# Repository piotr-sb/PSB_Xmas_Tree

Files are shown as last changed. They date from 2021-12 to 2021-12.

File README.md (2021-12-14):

# PSB_Xmas_Tree
PCB Xmas tree with LEDs

This little and fun project was created to bring smile to peoples face durig Xmas.

It is USB powered, easy to make Christmas tree with minimal number of components.

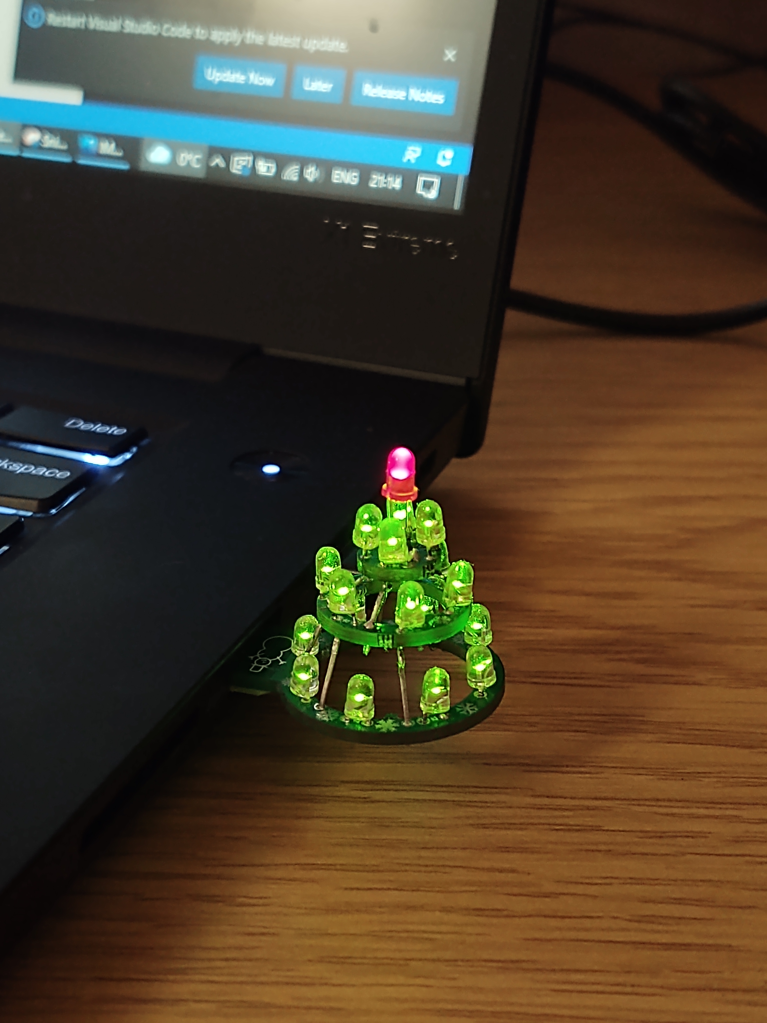
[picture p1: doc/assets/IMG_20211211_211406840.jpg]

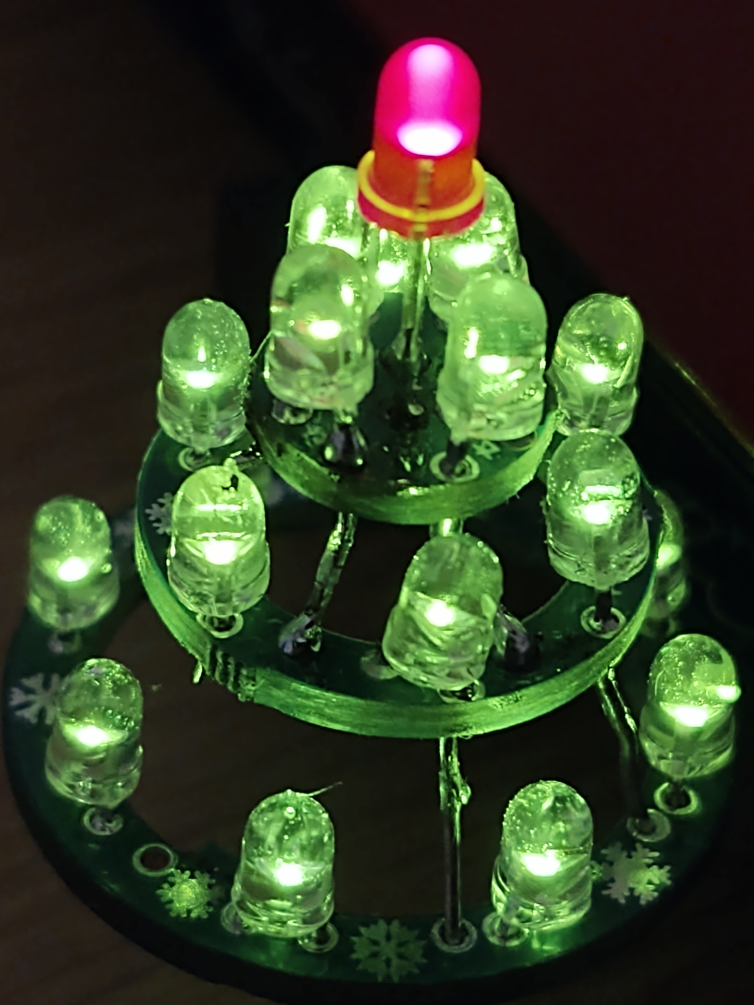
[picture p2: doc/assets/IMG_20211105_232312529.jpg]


## List of parts:
- 18x GREEN 3mm, THT LED
- 1x RED 3mm, THT LED
- 19x 1k 0603 resistor
- PCB

PCB was ordered from JLCPCB:

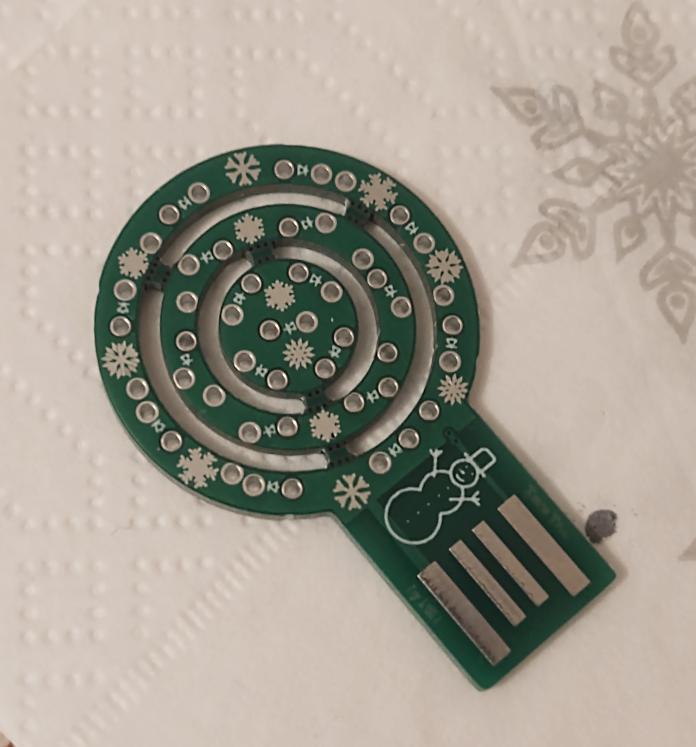
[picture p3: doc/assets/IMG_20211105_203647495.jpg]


LEDs legs are used also as mechanical support connecting layers together and providing power and GND. From each LED one leg needs to be cut short and the other one needs to be soldered to the layer below, because some of the connections are GND and some of them are +5V they can't be missmached, the connections should be as follows:

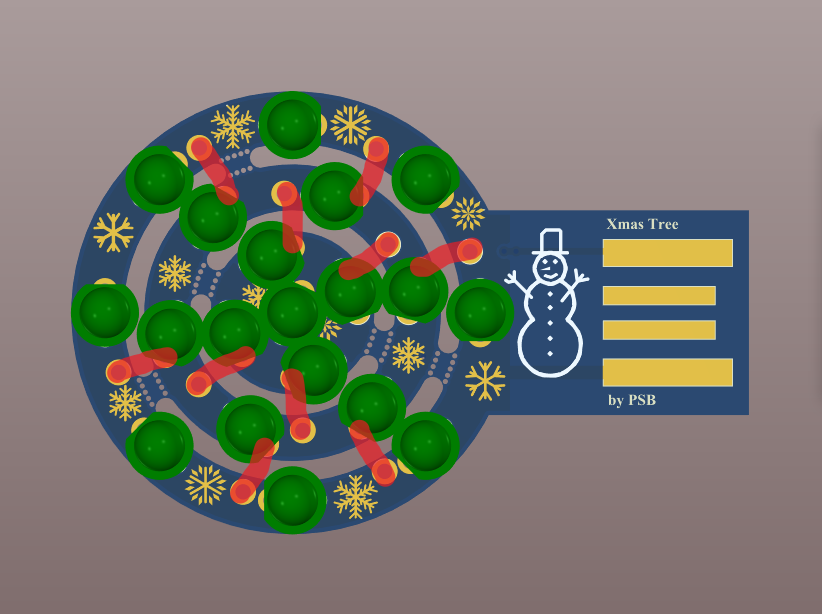
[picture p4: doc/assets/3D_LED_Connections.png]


The PCB is 1.6mm thick, which is not enough for the USB edge connector, this is why on the bottom side of the PCB a plasic psacer needs to be glued. I cut mine from some plastic bottle and used a universal glue.

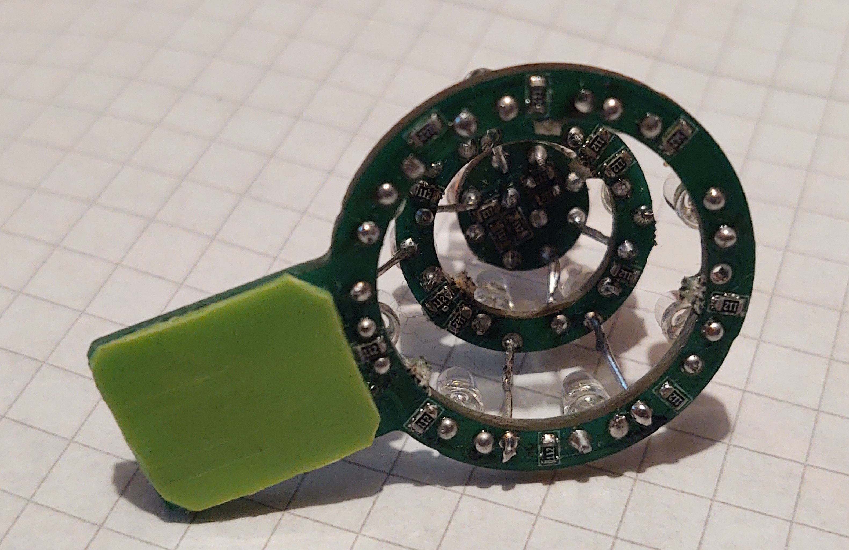
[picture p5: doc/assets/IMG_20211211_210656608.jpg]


I wish everyone a Happy Xmas time! Have a magical holiday season!

You can follow me on Twitter: https://twitter.com/Piotr_SB

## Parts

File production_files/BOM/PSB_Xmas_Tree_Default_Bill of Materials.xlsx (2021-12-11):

Fitted | Designator | Quantity | Value | Description | Footprint | Manufacturer | Manufacturer Part Number | PartNumber
Fitted | D1, D2, D3, D4, D5, D6, D7, D8, D9, D10, D11, D12, D13, D14, D15, D16, D17, D18, D19 | 19 |  | LED, THT 3mm, Green | LED_THT_Type_3mm_GREEN | FORYARD | FYL-3014PGC1A
Fitted | R1, R2, R3, R4, R5, R6, R7, R8, R9, R10, R11, R12, R13, R14, R15, R16, R17, R18, R19 | 19 | 1k | RES, 1k, 1%, 0.063 W, 0603 | R0603

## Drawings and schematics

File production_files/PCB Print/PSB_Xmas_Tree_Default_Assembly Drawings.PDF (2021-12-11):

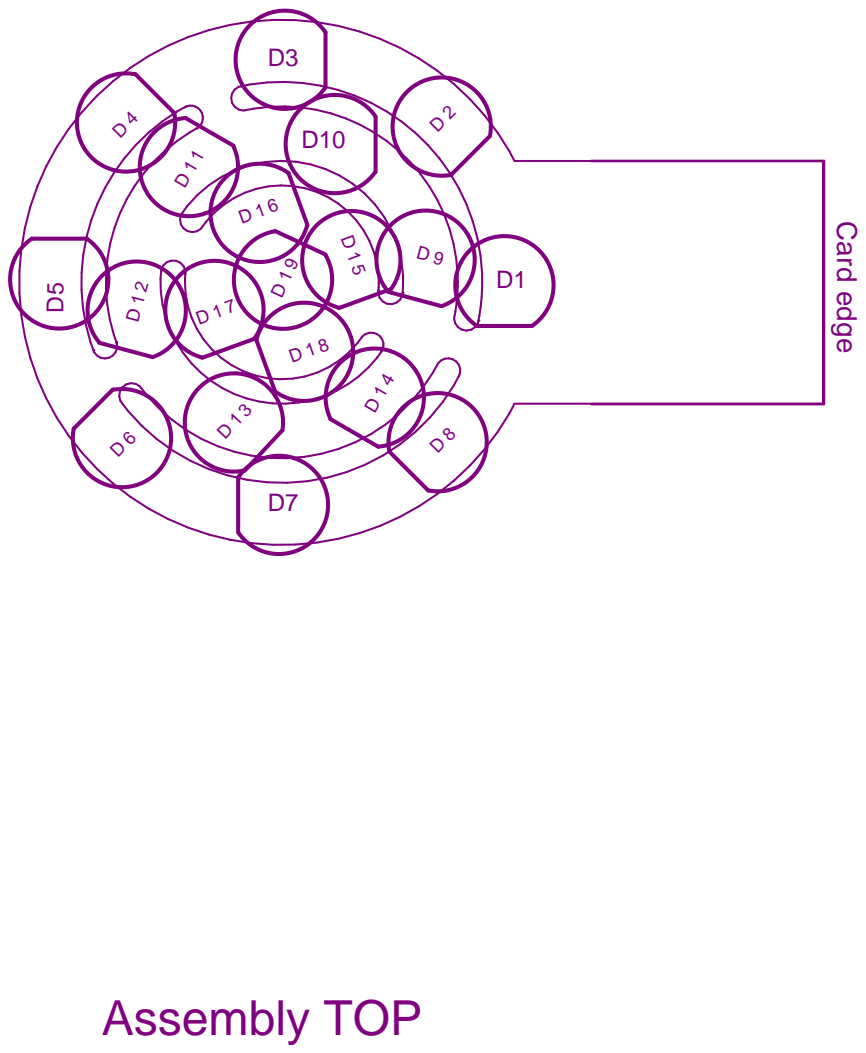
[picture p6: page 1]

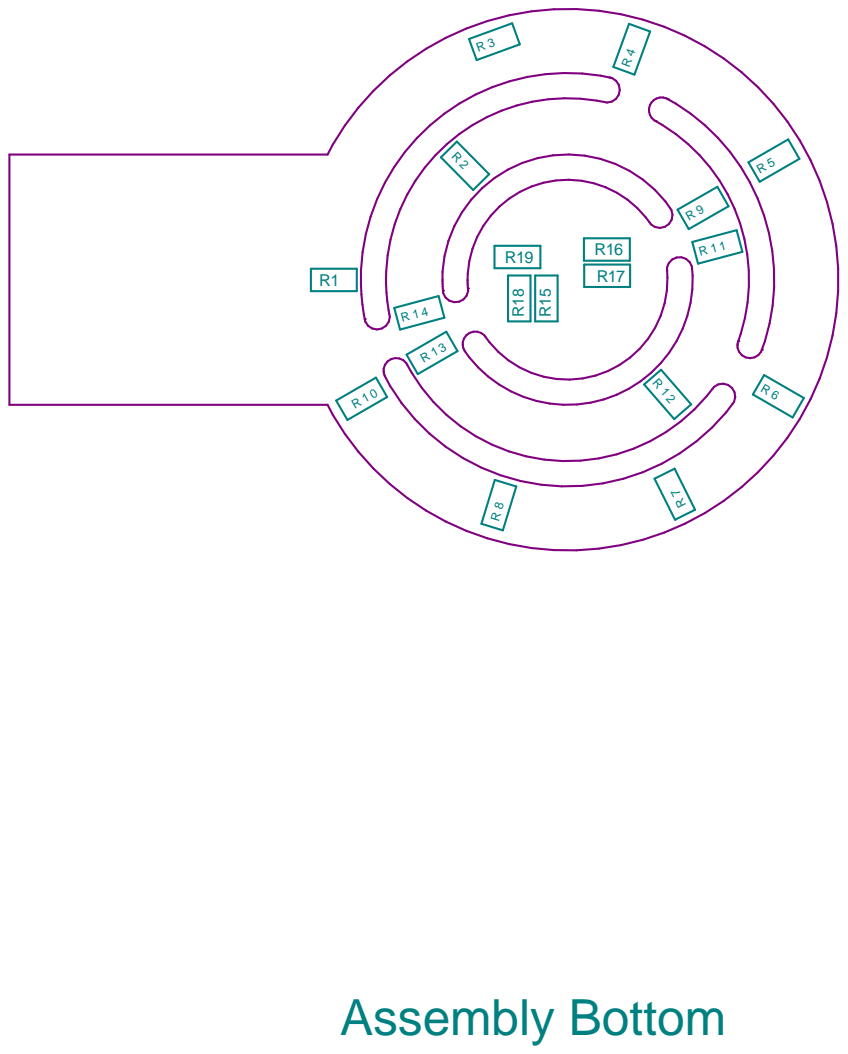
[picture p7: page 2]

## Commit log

2021-12-11 Initial Commit
    Added Design files to the repository
    [PSB_Xmas_Tree Project.SchDoc, PSB_Xmas_Tree.PrjPcb, [01] - COVER PAGE.SchDoc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]
2021-12-11 Added production files
    [PSB_Xmas_Tree_Default_Bill of Materials.xlsx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]
